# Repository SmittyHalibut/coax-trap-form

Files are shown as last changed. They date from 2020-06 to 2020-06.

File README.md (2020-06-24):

# coax-trap-form
Parametric OpenSCAD model for making coil forms for coax-traps for wire antennas.
The official home for these files is [https://github.com/SmittyHalibut/coax-trap-form](https://github.com/SmittyHalibut/coax-trap-form)
(Sorry Thingiverse, you're just a point-in-time snapshot when I think to make it.)
Look to github for the newest versions of all this.

# Electrical Design
Electrical design from the 2015 ARRL Antenna Handbook 
page 10-15, section 10.2.2, "Five Band W3DZZ Trap Antenna"
The idea is a trap resonant at 7.2MHz, which natively builds a 40/80m
antenna. But the series capacitance in the trap allows the total antenna
length to resonate at 20, 15, and 10m as well, at higher harmonics.
The idea being a 5 band antenna with only a single pair of traps.

The book shows two designs, depending on which diagram you look at:
1. Traps: 60pF, 8.2uH, 22' outer wire length
1. Traps: 100pF, 4.9uH, 21' outer wire length

Both have 32' inner length, and are fed with 75ohm.

My goal is to make these traps using the coax trap design discussed
later in the chapter.

# My Antenna
Using: https://www.qsl.net/ve6yp/coaxtrap.zip coax trap calculator, 
and C/ft numbers for coax I had on hand (RG8/X and RG58), I wasn't
able to make a coax trap with the exact values above; all common coax has
too much C/ft to get down to 100pF.  The best I could do was with my 
RG8/X, down to 137pF and 3.575uH, 6.25 turn on a 3.1in form.

The included STL is that form, with holes in the right places for coax and attachments.
Printed vertically like a tower, **THIS WILL NOT BE STRUCTURAL!**
My intention is to feed the antenna wire through a nylon rope so the 
rope is tensioned, but the wire is not.  The trap structure will just be loosely
hanging from the wire ends that stick out from the rope an inch or two.

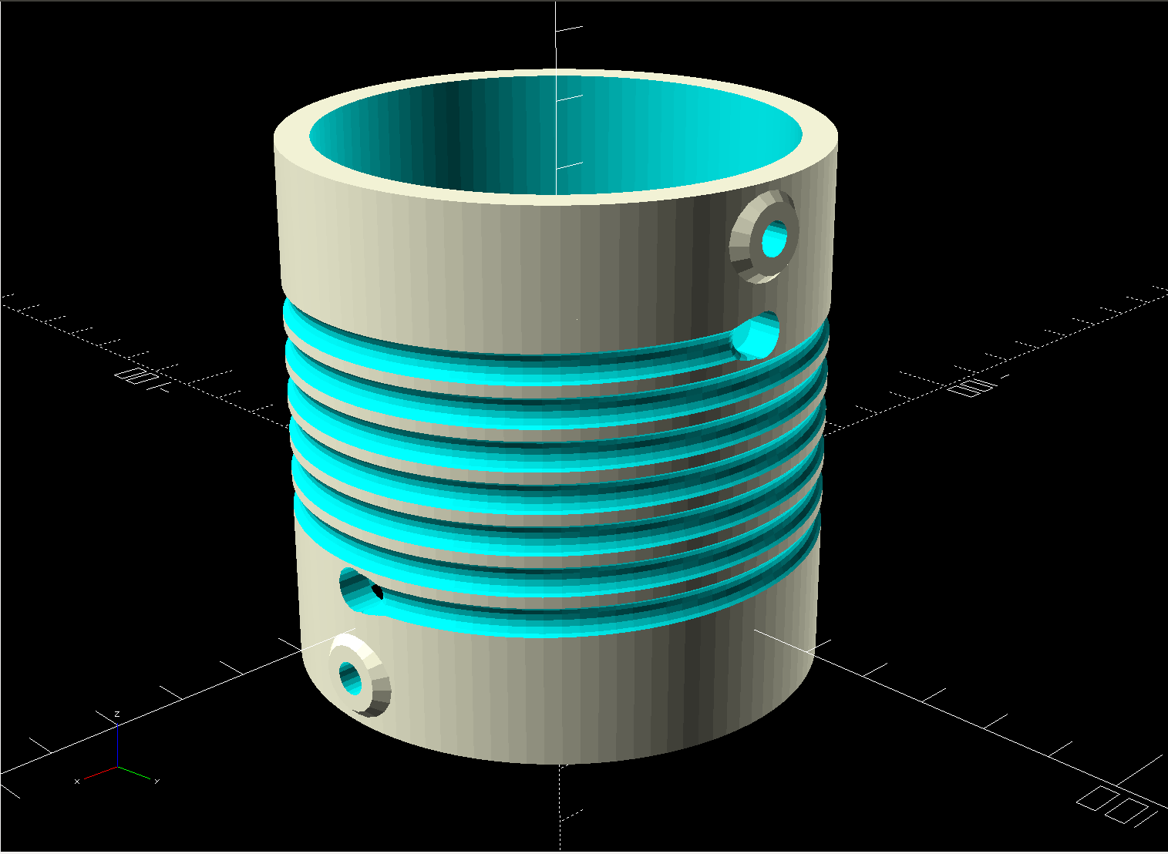
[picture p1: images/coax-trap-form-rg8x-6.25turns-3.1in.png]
Screen capture of my 3.1 inch, 6.25 turn form for RG8/X. Resonates at 7.200MHz


## 14.15MHz trap: 2.0 inch, 5.04 turns, RG8/X.
I also made a 20m trap at 14.15MHz, and included the STL for it.  The frequencies
are indicated in the file names.  Just in case I can't get the above 40m trap
antenna design to tune up on higher bands, I want an option for at least getting
on 20m during field day.  :-)

# Your Antenna!
But the OpenSCAD file is entirely parametric. 

Install [OpenSCAD](https://www.openscad.org/), open the `.scad` file, and adjust the parameters as listed below to make your own form.  Then Render the form (will take several minutes), and save your STL.  Then you can slice it as normal.

You can adjust the variables:
```
// Calculator: https://www.qsl.net/ve6yp/coaxtrap.zip
form_diameter_in = 3.1;
num_turns = 6.25;
// RG8/X, LMR240 = 0.242
coax_diameter_in = 0.242;
// No 10-24
bolt_diameter_in = 0.200;
form_thickness_in = .200;
```
# Show me your antenna!
If you build something with this model, I'd appreciate it if you sent me
a picture and/or description of what you built.  I'm [@SmittyHalibut on Twitter](https://twitter.com/SmittyHalibut).

73 de KR6ZY, @SmittyHalibut
-Mark

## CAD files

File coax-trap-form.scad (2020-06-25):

/*
 * The official home for these files is https://github.com/SmittyHalibut/coax-trap-form
 *
 * A form for a coax trap, to make a trap dipole
 * Electrical design from the 2015 ARRL Antenna Handbook 
 * page 10-15, section 10.2.2, "Five Band W3DZZ Trap Antenna"
 * The idea is a trap resonant at 7.2MHz, which natively builds a 40/80m
 * antenna. But the series capacitance in the trap allows the total antenna
 * length to resonate at 20, 15, and 10m as well, at higher harmonics.
 * The idea being a 5 band antenna with only a single pair of traps.
 * 
 * The book shows two designs, depending on which diagram you look at:
 * 1: Traps: 60pF, 8.2uH, 22' outer wire length
 * 2: Traps: 100pF, 4.9uH, 21' outer wire length
 * Both have 32' inner length, and are fed with 75ohm.
 * 
 * My goal is to make these traps using the coax trap design discussed
 * later in the chapter.
 * 
 * Using: https://www.qsl.net/ve6yp/coaxtrap.zip coax trap calculator, 
 * and C/ft numbers for coax I had on hand (RG8/X and RG58), I wasn't
 * able to make a coax trap with the values above; all common coax has
 * too much C/ft to get down to 100pF.  The best I could do was with my 
 * RG8/X, down to 137pF and 3.575uH, 6.25 turn on a 3.1in form.
 * 
 * This is that form, with holes in the right places for coax and attachments.
 * Printed vertically like a tower, THIS WILL NOT BE STRUCTURAL! 
 * My intention is to feed the antenna wire through a nylon rope so the 
 * rope is tensioned, but the wire is not.  The trap structure will just be loosely
 * hanging from the wire ends that stick out from the rope an inch or two.
 */
use <Writescad/Write.scad>

// Thingiverse Customizer displays the immediately preceeding comment. So 
// You'll see some duplication of comments below, with the last line being a shorter
// version to fit on one line for Thingiverse.  Sorry about that.
 
// What are the parameters of the form for your particular trap?
// The coil diameter. Calculator: https://www.qsl.net/ve6yp/coaxtrap.zip
form_diameter_in = 2.1;
// Number of turns (can be decimal, like 6.25) Calculator: https://www.qsl.net/ve6yp/coaxtrap.zip
num_turns = 1;

// What Coax are you using?
// RG8/X, LMR240 = 0.242
// RG58, LMR195 = 0.195
// What's the diameter of your coax?
coax_diameter_in = 0.242;

// Coil pitch: center-to-center spacing of turns. Not less than coax_diameter_in.
coax_pitch_in = 0.500;

// What size bolt are you using to attach to the antenna? 
// Oversize by ~10%; 3D printing isn't that precise, and OpenSCAD models circles with lines
// on the INSIDE of the circle, so the actual dimention is smaller than you think.
// No 10-24 = 0.200
// Size of the bolts you use to attach to antenna. Oversize by ~10%.
bolt_diameter_in = 0.200;

// How thick do you need the form to be?  Thicker is stronger, but is heavier and takes
// more material.  I find .150" to be pretty good, but adjust as you need.
// How thick should the form be?
form_thickness_in = .150;

// Text options
// Text on top half, opposite top hole
text_top = "20m";
// Text on bottom half, opposite bottom hole
text_bottom = "14.15MHz";

 
// Derived dimensions; you shouldn't need to change these:
// Don't change this in Thingiverse Customizer, it's a constant.
in2mm = 25.4;
form_diameter = form_diameter_in * in2mm;
coax_diameter = coax_diameter_in * in2mm;
coax_pitch = (coax_pitch_in < coax_diameter_in) ? coax_diameter : (coax_pitch_in * in2mm);
echo(coax_pitch);
bolt_diameter = bolt_diameter_in * in2mm;
form_thickness = form_thickness_in * in2mm;

coax_radius = coax_diameter/2;
coax_turns_height = coax_pitch * num_turns;
coax_turns_angle = num_turns * 360;
trap_length = coax_turns_height + coax_diameter*2;  // One diameter on either side for "slack"
extra_length = bolt_diameter*3;  // Additional form length on either side of the coil
bolt_surface_radius = bolt_diameter; 
bolt_surface_height = form_thickness*2;
total_body_length = trap_length + extra_length*2;

// Form is 1mm radius bigger than specified, so when we scoop out 1mm of turn for the
// coax, we're back to the desired diameter
form_radius = form_diameter/2;
form_radius_actual = form_radius + 1;

 
// Main form Body
difference() {
    cylinder(h=trap_length, r=form_radius_actual, center=false, $fn=100);
    // Take out the center core
    translate([0, 0, -1]) cylinder(h=trap_length+2, r=form_radius_actual-form_thickness, center=false, $fn=100);
    // Entry hole, at 0 degrees
    translate([form_radius, 0, coax_diameter]) {
        rotate(a=90, v=[0, 1, 0]) cylinder(h=form_thickness*2, d=coax_diameter*1.1, center=true, $fn=20);
        // Rounding the corners for coax bending into the inside.
        translate([-coax_radius*1.1, coax_radius*2, 0]) rotate(a=-90, v=[0, 0, 1])
            helix_extrude(angle=90, height=0, $fn=20) translate([coax_radius*2.0, 0, 0]) circle(r=coax_radius, $fn=20);
    }

    // Entry hole, at num_turns degrees
    rotate(a=num_turns*360, v=[0, 0, 1]) translate([form_radius, 0, coax_turns_height + coax_diameter]) {
        rotate(a=90, v=[0, 1, 0]) cylinder(h=form_thickness*2, d=coax_diameter*1.1, center=true, $fn=20);
        // Rounding the corners for coax bending into the inside.
        translate([-coax_radius*1.1, -coax_radius*2, 0]) 
            helix_extrude(angle=90, height=0, $fn=20) translate([coax_radius*2.0, 0, 0]) circle(r=coax_radius, $fn=20);
    }
    
    // Coax troff
    // Using built-in linear extrude; doesn't work. :-(
    //translate([0, 0, coax_diameter])
    //   #linear_extrude(height = coax_turns_height, center=false, convexity=10, twist = 360*num_turns, $fn=100) 
    //       translate([form_radius + coax_diameter/2, 0, 0])
    //           circle(r=coax_diameter/2);
    
    // Using occamsshavingkit code from github. Works, but doesn't render?
    //$fn=50;
    //coax = he_rotate([90, 0, 0], he_translate([form_radius+coax_radius, 0, 0], he_circle(coax_diameter)));
    //translate([0, 0, coax_diameter])
    //    helix_extrude(shape=coax, pitch=coax_diameter, rotations=num_turns);
    
    // Using thingiverse code
    translate([0, 0, coax_diameter])
        helix_extrude(angle=coax_turns_angle, height=coax_turns_height, $fn=100)
           translate([form_radius + coax_radius, 0, 0])
               circle(r=coax_radius, $fn=20);
               
    
    
}
// Extra bit on top
translate([0, 0, trap_length]) {
    difference() {
        union() {
            difference() {
                cylinder(h=extra_length, r=form_radius_actual, center=false, $fn=100);
                // Take out the center core
                translate([0, 0, -1]) cylinder(h=extra_length+2, r=form_radius_actual-form_thickness, center=false, $fn=100);
            }
            rotate(a=num_turns*360, v=[0, 0, 1]) {
                // Bolt surface, outside
                translate([form_radius_actual, 0, bolt_diameter*1.5]) rotate(a=90, v=[0, 1, 0])
                    cylinder(h=form_thickness/2, d2=bolt_diameter*2, d1=bolt_diameter*3, center=true, $fn=20);
                // Bold surface, inside
                translate([form_radius_actual-form_thickness, 0, bolt_diameter*1.5]) rotate(a=90, v=[0, 1, 0])
                    cylinder(h=form_thickness/2, d1=bolt_diameter*2, d2=bolt_diameter*3, center=true, $fn=20);
                // Text
                rotate(a=-90, v=[0, 0, 1]) 
                    writecylinder(text_top, where=[0, 0, bolt_diameter*1.5], radius=form_radius_actual, height=0,
                        h=bolt_diameter*2);
            }
        }
        // Mount hole for hardware
        rotate(a=num_turns*360, v=[0, 0, 1])
            translate([form_radius-form_thickness/2, 0, bolt_diameter*1.5]) rotate(a=90, v=[0, 1, 0])
                cylinder(h=bolt_surface_height*2, d=bolt_diameter, center=true, $fn=20);
    }
        
}
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

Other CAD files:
Writescad/Letters.dxf
Writescad/Write.scad

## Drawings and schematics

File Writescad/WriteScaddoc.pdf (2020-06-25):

p1

## WriteScad

By Harlan Martin
harlan@sutlog.com
January 2012

Version 2
Added support for future font selection (default is Letters.dxf) Added WriteCube module
Added Rotate for text (rotates on the plane of the text)
Added writesphere module

NOTE: These routines require openscad version 2011.12 or later

http://www.openscad.org/

-o-

## write()

Note about strings:
1... | The quote " symbol cannot be inserted into a string alone Either use \" or just the single quote' will show as "
2... | The \ is used for special text characters, so use the bar | to show the back slash \

Usage

Put the files (write.scad) and (letters.dfx) in the
| same directory as your project.

write("Hello World!",t=3,h=5,center=true);

(t=mm) (optional) The thickness of the letters in mm.
| The default is 1mm if not specified

(h=mm)(optional) The height of the letters in mm.
| The default is 4mm if not specified

(rotate=degrees) Rotates the text along the plane it is written on.

(center=boolean) (optional) Centers the text at default coordinates. Examples:

use <write.scad> // Dont forget to include this line

//example1: Uses all declarations..
| translate([20,15,0]) write("Example 1",t=4,h=5.75,center=true);

//example2: Quick and easy
| write("That was easy!",h=12);

//example3: move and rotate(front) (remember to translate..then rotate)
| translate([0,0,10]) rotate(90,[1,0,0]) // rotate around the x axis write("Rotate +X 90 (front)",t=2);

//example4: move and rotate(left side)
| translate([0,0,20]) rotate(90,[1,0,0]) // rotate around the x axis rotate(90,[0,-1,0]) // rotate around the y axis write("Rotate +X 90 and -Y 90 (left side)");

//example5: move and rotate(right side)
| translate([0,0,30]) rotate(90,[1,0,0]) // rotate around the x axis rotate(90,[0,1,0]) // rotate around the y axis write("Rotate +X 90 and +Y 90 (right side)");

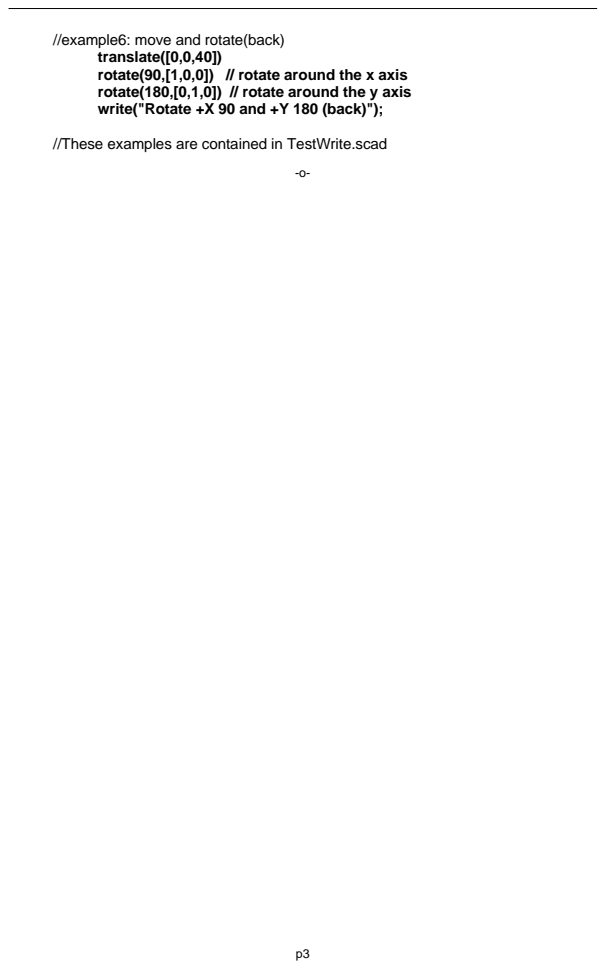
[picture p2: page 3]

//example6: move and rotate(back)

translate([0,0,40])
rotate(90,[1,0,0]) // rotate around the x axis
rotate(180,[0,1,0]) // rotate around the y axis
write("Rotate +X 90 and +Y 180 (back)");

//These examples are contained in TestWrite.scad

## writecube()

For these examples, assume we have the cube: use <write.scad>
translate([10,20,30])
cube(30,center=true);
text where and size
The values for text=, where= and size= are required, but if the values are entered in this order, then the commands are not required. These three examples produce the same results.

writecube(text="text", where=[10,20,30], size=[30,30,30]); or
writecube("text",[10,20,30], [30,30,30]);
or
writecube("text",[10,20,30],30);

text is written on the center front of a cube that is 30mm on all sides, and is centered at [10,20,30]

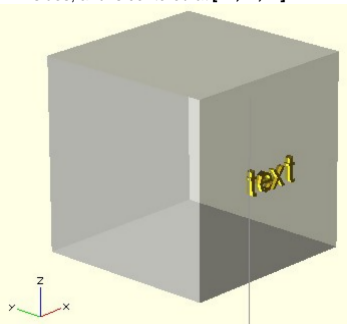
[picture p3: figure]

text="whatever text you want to write"
where= the center coordinates of the box
size = size of cube. If the cube is not square, use the format [xsize,ysize,zsize] If it is the same on all sides, just give the size ie. 30
face=
By default, writecube() will write on the front face of the box.
This assumes that x=left to right, y=front to back, z=bottom to top. To write on the other sides, use: face="top",face="bottom",face="back",face="front", face="left" or face="right"

writecube("Howdy!!",[10,20,30],30,face="left");

will print Howdy!! on the center left of the box.

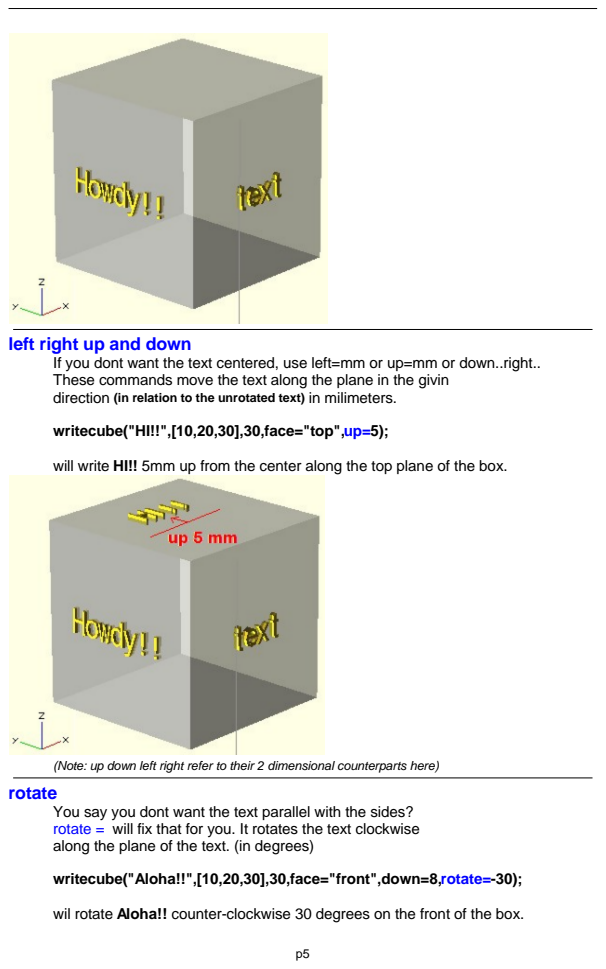
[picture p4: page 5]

left right up and down

If you dont want the text centered, use left=mm or up=mm or down..right..
These commands move the text along the plane in the givin
direction (in relation to the unrotated text) in milimeters.

writecube("HI!!",[10,20,30],30,face="top",up=5);

will write HI!! 5mm up from the center along the top plane of the box.

(Note: up down left right refer to their 2 dimensional counterparts here)
rotate

You say you dont want the text parallel with the sides?
rotate = will fix that for you. It rotates the text clockwise
along the plane of the text. (in degrees)

writecube("Aloha!!",[10,20,30],30,face="front",down=8,rotate=-30);

wil rotate Aloha!! counter-clockwise 30 degrees on the front of the box.

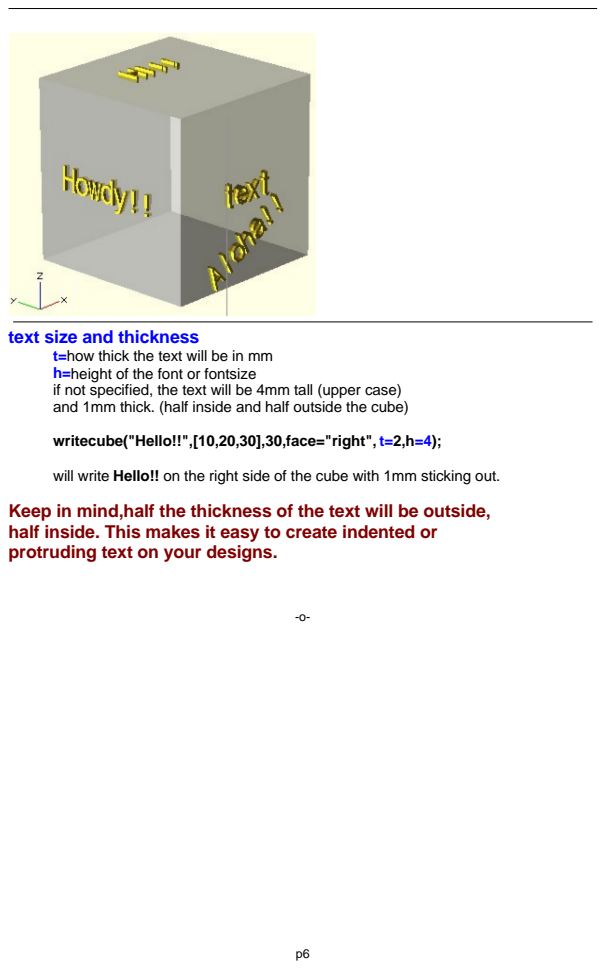
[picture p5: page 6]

text size and thickness

t=how thick the text will be in mm
h=height of the font or fontsize
if not specified, the text will be 4mm tall (upper case)
and 1mm thick. (half inside and half outside the cube)

writecube("Hello!!",[10,20,30],30,face="right", t=2,h=4);

will write Hello!! on the right side of the cube with 1mm sticking out.
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

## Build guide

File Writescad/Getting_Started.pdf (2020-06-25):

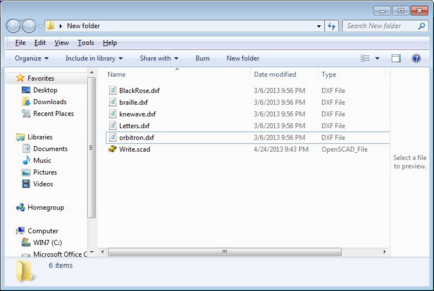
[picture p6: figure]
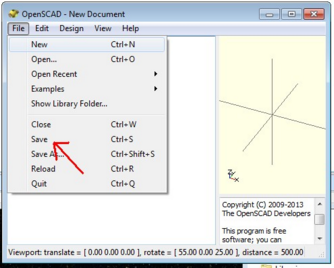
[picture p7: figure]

p1

Harlan

## Getting Started

Create a new folder on your desktop..

copy the folowing files to the new folder: Write.scad
BlackRose.dxf
braille.dxf
knewave.dxf
Letters.dxf
orbitron.dxf

Start openscad
click file.. save..

Find the new folder you created on your desktop and save your blank openscad file..

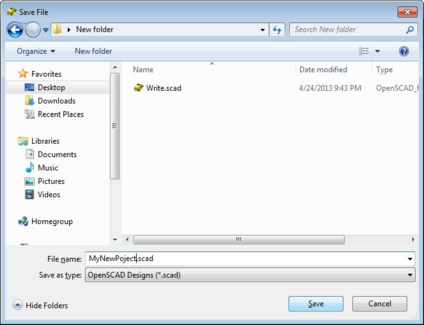
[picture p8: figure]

Your working folder (the new one you created on the desktop) will now contain write.scad, the dxf files (fonts) and your new project.

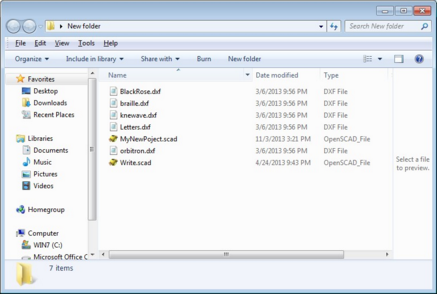
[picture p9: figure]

Now lets create an example.

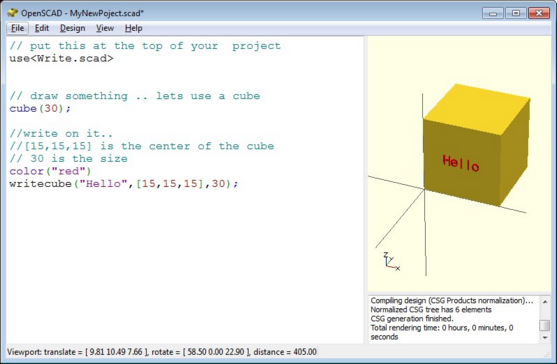
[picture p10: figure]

The use<Write.scad> tells openscad to use the routines in the write.scad file with the project you are working on..

-o-

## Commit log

2020-06-21 Parametric OpenSCAD model for coil form for coax traps for wire antennas.
    [coax-trap-form.scad]
2020-06-21 Made the parameters in .scad formatted better for editing, and usable with Thingiverse's Customizer tool. And cleaned up documentation a bit.
    [coax-trap-form.scad]
2020-06-21 STL: Not entirely sure what changed, but this is just an STL from the most recent .scad file. README.md: Updated comments around parameters to work better with Thingiverse Customizer app.
    [coax-trap-form.scad]
2020-06-24 Making a 14.15MHz trap: rg8x, 5.04 turns, 2.0in form. Otherwise, similar to the 7.2MHz trap. (Oh, renamed the 7.2MHz to signify it's a 7.2MHz trap form.)
    [coax-trap-form.scad]
2020-06-25 Imported Writescad library from https://www.thingiverse.com/thing:16193 . Added text to traps. Added optional larger-than-coax pitch for loosely spaced coils.
    [Letters.dxf, Write.scad, coax-trap-form.scad]
2020-06-25 Actually made changes mentioned in the last commit (helps when you save your changes.)
    [coax-trap-form.scad]
